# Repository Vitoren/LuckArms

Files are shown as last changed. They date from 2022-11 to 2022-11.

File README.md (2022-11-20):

# LuckArms

This repository contains both the 3D models and the code which I am using for my Luck cosplay with the lightning armor. It is worth noting that the parts are pretty big, but I sized them to fit me specifically so it may require some modifications to make them fit you. 

<b>What is in the REPO</b>

Models:

In this repository, I have the third (most recent) version of my 3D models, as well as two arduino files with my code. The HandAgainV3g file has the fingers attached to the hand, while the fingerlesshand file only has the thumb attached. That folder also contains each of the fingers separately for use with the fingerless hand (although the models do not have a joint for them to be attached to, so I would just use tape or glue).

The leg models from V2 are also posted here - I did not remodel them as part of V3 so V2 is the latest version of those. There are uploads of those files both with and without holes for the LEDs (version 2 had holes that the LEDs could fit into) and like the arms there are minimal joints. The bottom part of the leg-top model is designed to slide into the slit at the top of the shoe model and the heel of the shoe has shapes which help hold it in place with the rest of the shoe (particularly when the leg top is also in the slot). 

Code: 

The lightningcode5 file is meant to be used with only one programmable LED strip. The onestripcondensed file is meant to be used in combination with a demultiplexor to run several (up to 8) LED strips off of one arduino.

  <b>What I did</b>

Printed using: Artillery Sidewinder x2 with this filament: https://www.amazon.com/dp/B07N1FD3GL?psc=1&ref=ppx_yo2ov_dt_b_product_details.

I use the Cura slicer, and would recommend using the "tree" support structure as opposed to the default since it makes the supports much easier to remove once the model is done printing.

For the circuits, I am using an Arduino Nano powered by a basic portable cell phone charger and several programmable LED strips for the lights. The lights are programmed using the FastLED library. I am also using a demultiplexor (https://www.amazon.com/dp/B016G4MQH8?psc=1&ref=ppx_yo2ov_dt_b_product_details) so I can use bit-packing to run more LEDs than would otherwise be possible given the limited memory of the arduino nano. 

Hope this helps!

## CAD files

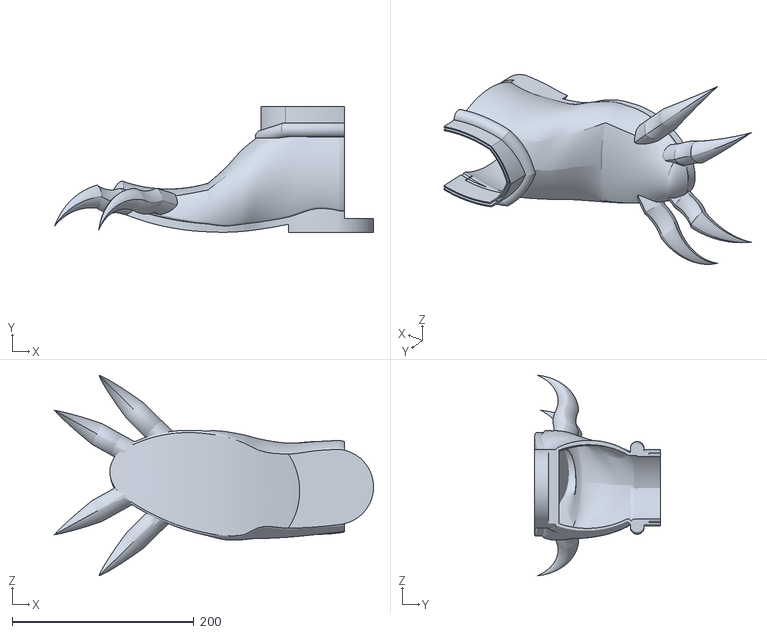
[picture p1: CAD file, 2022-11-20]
legmodel/shoe-noholes.stl
350.8 x 138.1 x 220.7

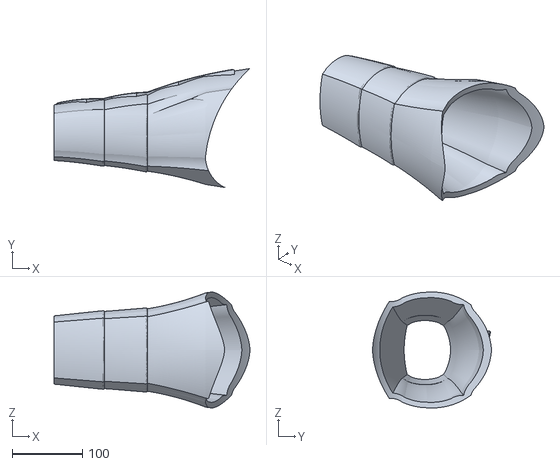
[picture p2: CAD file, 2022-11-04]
V3/upperarm.stl
279.4 x 169.6 x 165.3

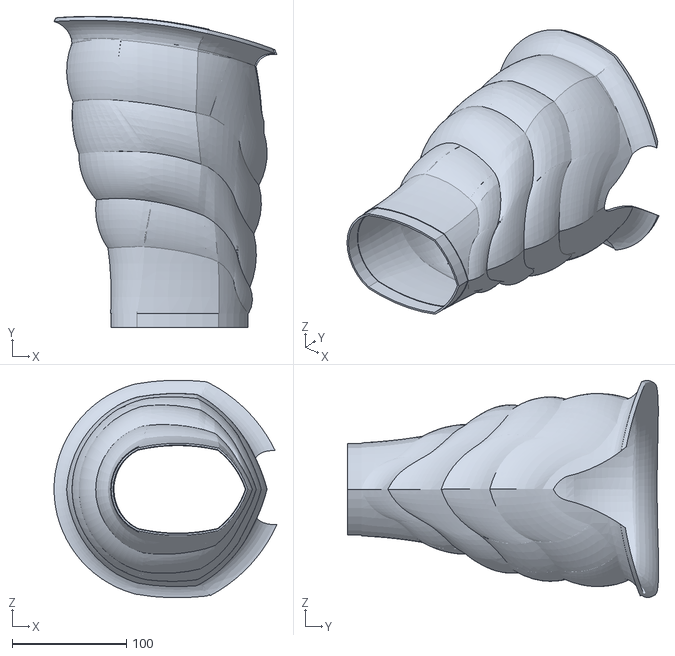
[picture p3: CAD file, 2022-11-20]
legmodel/legtop-noholes.stl
195.4 x 272.7 x 190.5

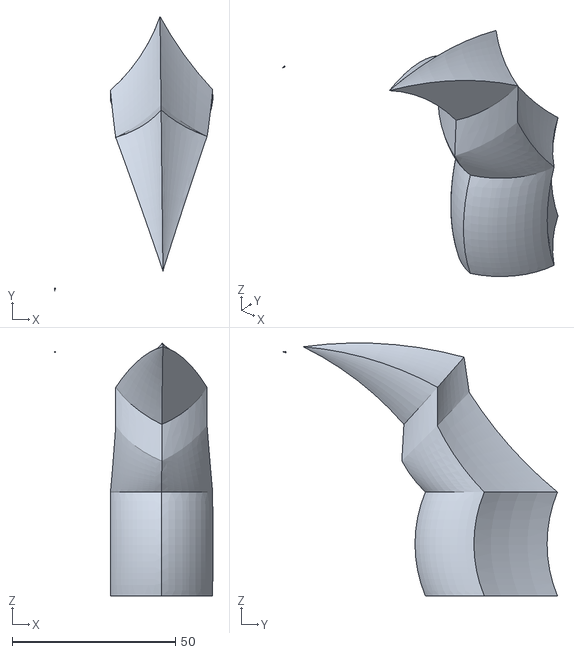
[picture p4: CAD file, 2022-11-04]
V3/pointer.stl
48.5 x 83.8 x 77.3

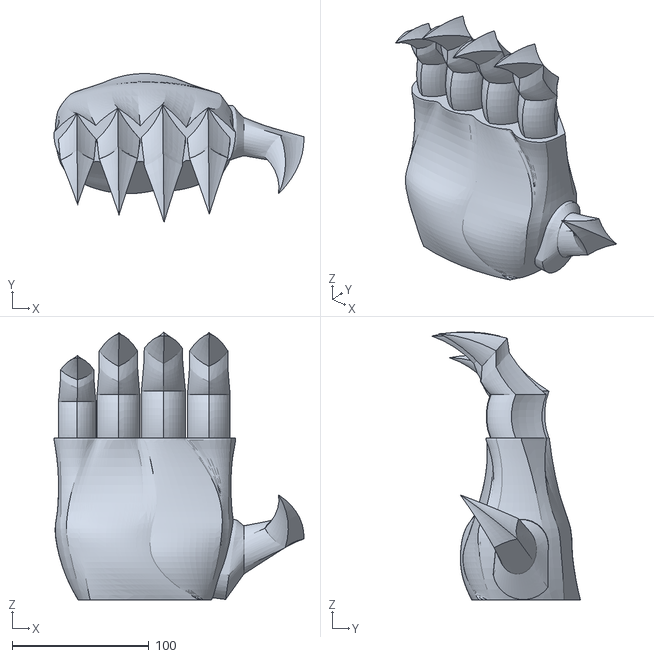
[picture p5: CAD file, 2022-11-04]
V3/HandAgainV3g.stl
182.4 x 108.7 x 195.7

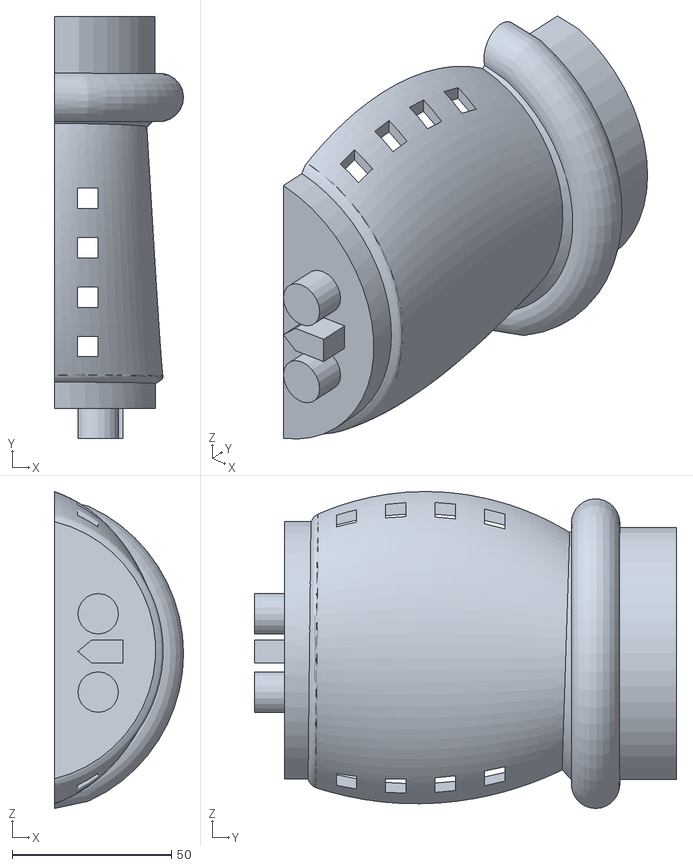
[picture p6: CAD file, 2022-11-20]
legmodel/shoeback.stl
40.5 x 132.4 x 99.4

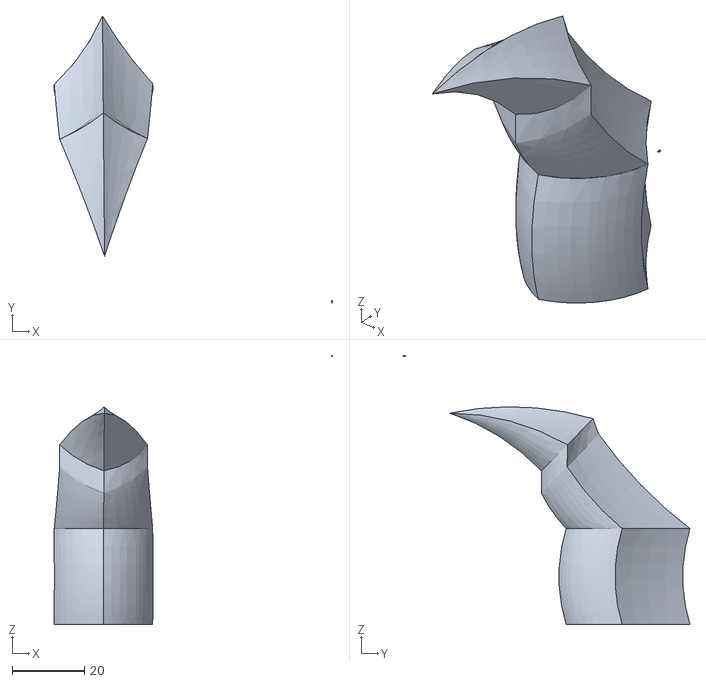
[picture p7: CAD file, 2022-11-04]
V3/pinkey.stl
77.4 x 79.7 x 74.8

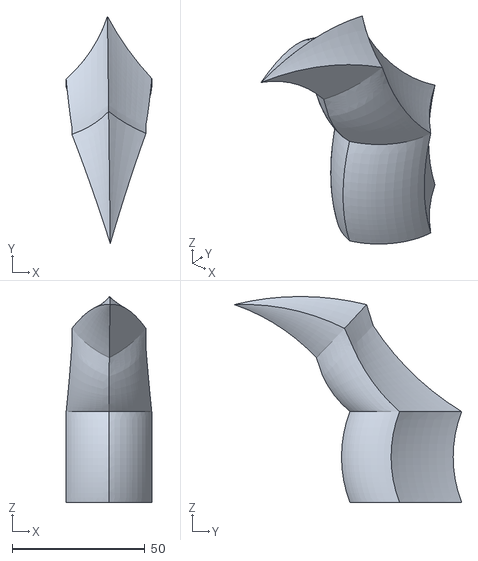
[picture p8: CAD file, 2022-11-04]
V3/middle.stl
32.3 x 85.7 x 77.7

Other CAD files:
legmodel/legtop.stl
legmodel/shoeback-noholes.stl

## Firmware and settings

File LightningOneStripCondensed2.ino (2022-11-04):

 #include <FastLED.h>

//config
//some good ones: maxL = 20, maxSim = 12
const short max_times = 5; //max number times a flash can repeat

const int flash_delay_min = 12; //minimum delay between a flash turning on and off was 5 15
const int flash_delay_max = 35; //maximum delay between a flash turning on and off
const short max_sim = 3; //max simultaneous flashes

const int fcol [] = {120,120,255}; //flash color //blue-white 
const int ncol [] = {1,5,30};

const short maxLength = 180; //max flash length (leds)
const short minLength = 70; // min flash length

const int max_wait = 1500; //maximum time to wait before issuing a new flash section after one finishes
const int max_tries_to_enter = 3; //max number of times random coords will be generated when trying to add a new flash block

//Number of LEDS per strip
const int numLeds = 288;

//Total # of leds across all strips
const int total_leds = 1300;

//global var (for efficiency)
int count = 0;
int start;
int fin;
bool ok;
int fdel;
int maxFlashes;
int i;
int j;
int temp;

int stripNum;

//Pin numbers
int sel0 = 5;
int sel1 = 6;
int sel2 = 7;

int switchDelay = 1;

CRGB leds[numLeds];

byte strip[numLeds];

typedef struct //data structure for a flash block
  {
    bool on; //currently on or off
    bool valid;
    int st; //start index
    int en; //end index
    int maxF; // max # of flashes
    int del; //flash delay
    int timesF; //times flashed
    long nextT; //time of next update
  } flash_t;

flash_t flashes [max_sim];

flash_t check;
void setup(){
  //Set the ports
  pinMode(sel0,OUTPUT); //A
  pinMode(sel1,OUTPUT); //B
  pinMode(sel2,OUTPUT); //C
  
  FastLED.addLeds<WS2812, 3, GRB>(leds, numLeds);
  Serial.begin(9600);

  //set the flash array to be all invalid and be updated when first ran
  for(i = 0; i<max_sim; ++i){
    flashes[i].valid = false;
    flashes[i].nextT = millis()+i*100;
  }
  //Set all the leds to the non-flash color
  for(i = 0; i<numLeds; ++i){
    leds[i] = CRGB(ncol[0],ncol[1],ncol[2]);
  }

  digitalWrite(sel0,LOW);
  digitalWrite(sel1,LOW);
  digitalWrite(sel2,LOW);
  delay(switchDelay);
  FastLED.show();
  delay(switchDelay);
  digitalWrite(sel0,HIGH);
  delay(switchDelay);
  FastLED.show();
  delay(switchDelay);
  digitalWrite(sel0,LOW);
}

bool getBit(int index){
    return strip[index%numLeds]&(1<<(index/numLeds));
}

void setBit(int index,bool value){
    if(value){
        strip[index%numLeds]=strip[index%numLeds]|(1<<(index/numLeds));
    }
    else{
        strip[index%numLeds]=strip[index%numLeds]&(~(1<<(index/numLeds)));
    }
}

void setPorts(){
    if(stripNum==0){
      digitalWrite(sel0,LOW);
      digitalWrite(sel1,LOW);
      digitalWrite(sel2,LOW);
    }
    else if(stripNum == 1){
      digitalWrite(sel0,HIGH);
      digitalWrite(sel1,LOW);
      digitalWrite(sel2,LOW);
    }
    else if(stripNum == 2){
      digitalWrite(sel0,LOW);
      digitalWrite(sel1,HIGH);
      digitalWrite(sel2,LOW);
    }
    else if(stripNum == 3){
      digitalWrite(sel0,HIGH);
      digitalWrite(sel1,HIGH);
      digitalWrite(sel2,LOW);
    }
    else if(stripNum == 4){
        digitalWrite(sel0,LOW);
        digitalWrite(sel1,LOW);
        digitalWrite(sel2,HIGH);
    }
    else if(stripNum == 5){
        digitalWrite(sel0,HIGH);
        digitalWrite(sel1,LOW);
        digitalWrite(sel2,HIGH);
    }
}

void showLeds(int st, int en){
    for(i=st;i<=en;++i){
        //Change to a different strip if necessary
        if(stripNum != i/numLeds){
            if(i != st){ //no unshown changes have been made if i=st when the stripnum is different
                FastLED.show();
            }
            stripNum=i/numLeds;
            setPorts();
            //Sync the LED array with packed data
            for(j = 0; j<numLeds; j++){
                if(getBit(j + stripNum*numLeds)){
                    leds[j] = CRGB(fcol[0],fcol[1],fcol[2]);
                }
                else{
                    leds[j] = CRGB(ncol[0],ncol[1],ncol[2]);
                }
            }
        }
        //Set the LED array
        if(getBit(i)){
            leds[i%numLeds] = CRGB(fcol[0],fcol[1],fcol[2]);
        }
        else{
            leds[i%numLeds] = CRGB(ncol[0],ncol[1],ncol[2]);
        }
    }
    FastLED.show();
}

//finds a valid start position for a flash block
void setSP(flash_t* f, flash_t flashes[]){
    for(count = 0; count < max_tries_to_enter; ++count){
    //generate random start and end points
    start = micros()%(total_leds-minLength);
    fin = start+ (micros()%(maxLength-minLength))+minLength;
    //make the flash block in bounds if it exceeds the max number of leds
    if(fin >= total_leds){
      fin = total_leds-1;
    }
    //ensure the flash block doesnt overlap with another
    ok = true;
    for(i = 0; i<max_sim; ++i){
      check = flashes[i];
      if(check.valid){
        if(start >= check.st && start < check.en){
          ok = false;
          break;
        }
        if(fin >= check.st && fin <= check.en){
          ok = false;
          break;
        }
      }
    }
    //if the block doesnt overlap with another, set the start and end values, make it valid and return.
    if(ok){
      f->st = start;
      f->en = fin;
      f->valid = true;
      return;
    }
  }
}

//update each of the flash blocks

void flashUpdate(flash_t* f,flash_t flashes[]){
  if(millis() >= f->nextT){
    if(f->valid){
      if(f->on){ //turn it off
        for(i = f->st; i<=f->en;++i){
          setBit(i,0);
        }
        f->on = false;
        f->nextT = millis()+(f->del);
        showLeds(f->st,f->en);
       
        if(f->maxF == f->timesF){
          f->valid = false;
          f->nextT = millis() + (micros()%max_wait);
        }
      }
    //turn lights on
      else{
        for(i = f->st; i<= f->en; ++i){
          setBit(i,1);
        }
        showLeds(f->st,f->en);
        f->on = true;
        f->timesF = (f->timesF)+1;
        f->nextT = (f->del)+millis();
      }
    }
    else{ //flash invalid, make a new one
      setSP(f,flashes);
      fdel = (micros()%(flash_delay_max-flash_delay_min))+flash_delay_min;
      maxFlashes = (micros()%max_times)+1;
      //put em in
      f->del = fdel;
      f->maxF = maxFlashes;
      //set other vals
      f->on = false;
      f->timesF = 0;
      f->nextT = 0;
    }
  }
}

void loop(){
  for(i = 0; i<max_sim; ++i){
    flashUpdate(&flashes[i],flashes);
  }
}

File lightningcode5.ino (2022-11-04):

#include <FastLED.h>

//config
//some good ones: maxL = 20, maxSim = 12
const short max_times = 5; //max times a flash will repeat
const int flash_delay_min = 7;
const int flash_delay_max = 20;
const short max_sim = 1; //max simultaneous flashes
const int fcol [] = {150,175,255}; //flash color //light blue
const int ncol[] = {2,25,40};
const int ecol [] = {ncol[0]+10,ncol[0]+10,ncol[2]+40};
const short maxLength = 100; //max flash length (leds) was 35
const short minLength = 50; // min flash length
const short ext = 0; //how far to make the light flash extend (the dimmer part)
const int numLeds = 200; //was 195
const int max_wait = 1500; //time to wait before issuing a new sequence
const int max_tries_to_enter = 10; //max number of times random coords will be generated when adding a sequence

CRGB leds[numLeds];
typedef struct 
  {
    bool on; //currently on or off
    bool valid;
    int st; //start index
    int en; //end index
    int maxF; // max # of flashes
    int del; //flash delay
    int timesF; //times flashed
    long nextT; //time of next update
  } flash_t;

flash_t flashes [max_sim];

void setup(){
  FastLED.addLeds<WS2812, 2, GRB>(leds, numLeds);
  Serial.begin(9600);
  for(int i = 0; i<max_sim; ++i){
    flashes[i].valid = false;
    flashes[i].nextT = 0;
  }
  for(int i = 0; i<numLeds; ++i){
    leds[i] = CRGB(ncol[0],ncol[1],ncol[2]);
  }
  FastLED.show();
}

void setSP(flash_t* f){
  int count = 0;
  while(count < max_tries_to_enter){
    int start = micros()%(numLeds-minLength); //adjust this
    int fin = start+ (micros()%(maxLength-minLength))+minLength;
    if(fin >= numLeds){
      fin = numLeds-1;
    }
    bool ok = true;
    flash_t check;
    for(int i = 0; i<max_sim; ++i){
      check = flashes[i];
      if(check.valid){
        if(start >= check.st && start < check.en){
          ok = false;
        }
        if(fin >= check.st && fin <= check.en){
          ok = false;
        }
      }
    }
    if(ok){
      f->st = start;
      f->en = fin;
      f->valid = true;
      return;
    }
    count++;
  }
}


void flashUpdate(flash_t* f){
  if(millis() >= f->nextT){
  if(f->valid == false && millis()>= f->nextT){ //make a new flash
    //make values
    setSP(f);
    int fdel = (micros()%(flash_delay_max-flash_delay_min))+flash_delay_min;
    int maxFlashes = (micros()%max_times)+1;
    //put em in
    f->del = fdel;
    f->maxF = maxFlashes;
    //set other vals
    f->on = false;
    //f->valid = true;
    f->timesF = 0;
    f->nextT = 0;
  }
  //time to update
  if(f->valid && millis()>= f->nextT){
    //currently mid-flash
    if(f->on){
      //turn off the lights
      for(int j = (f->st)-ext; j <= (f->en)+ext; ++j){
        if(j >=0 && j<numLeds){
          leds[j] = CRGB(ncol[0],ncol[1],ncol[2]);
        }
      }
      f->on = false;
      f->nextT = millis()+(f->del);
      FastLED.show();
      //if done flashing, make it invalid
      if(f->maxF == f->timesF){
        f->valid = false;
        f->nextT = millis()+(micros()%max_wait);
      }
    }
    else{
      //turn on lights (main flash)
      for(int j = f->st; j<= (f->en); j++){
        leds[j] = CRGB(fcol[0],fcol[1],fcol[2]);
      }
      //turn on lights (flash extend)
      
      for(int j = 1; j<=ext; j++){
        if((f->en)+j < numLeds){
          leds[(f->en)+j] = CRGB(ecol[0],ecol[0],ecol[2]);
        }
        if((f->st)-j >= 0){
          leds[(f->st)-j] = CRGB(ecol[0],ecol[0],ecol[2]);
        }
      }
      
      FastLED.show();
      //do other stuff
      f->on = true;
      f->timesF = (f->timesF)+1;
      f->nextT = (f->del)+millis();
    }
  }
  }
}

void printFlash(int index){
  Serial.print(index);
  Serial.print(": Start: ");
  Serial.print(flashes[index].st);
  Serial.print(" End: ");
  Serial.print(flashes[index].en);
  Serial.print(" #fs: ");
  Serial.print(flashes[index].timesF);
  Serial.print(" maxF: ");
  Serial.print(flashes[index].maxF);
  Serial.print(" nextUpdate: ");
  Serial.print(flashes[index].nextT);
  Serial.println();
  
}

void loop(){
  for(int i = 0; i<max_sim; ++i){
    //printFlash(i);
    flashUpdate(&flashes[i]);
  }
}

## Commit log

2022-11-04 Add files via upload
    These are the current V3 3D models of the lightning arms
    [HandAgainV3g.stl, middle.stl, pinkey.stl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]
2022-11-04 Add files via upload
    Code for a single programmable LED strip with lightning effects
2022-11-04 Add files via upload
    Code to be used with the multiplexor to run multiple programmable LED strips
2022-11-20 Leg models
    Note: These are from version 2 - I did not remodel them for V3
2022-11-20 Leg models
    Note: These are part of V2 - I did not remodel them for V3
    [legtop-noholes.stl, legtop.stl, shoe-noholes.stl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]
